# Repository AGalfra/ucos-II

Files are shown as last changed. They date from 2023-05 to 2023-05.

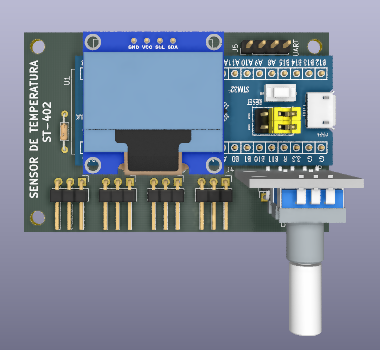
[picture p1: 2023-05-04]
vista2.png

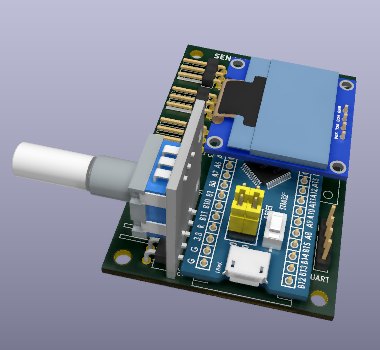
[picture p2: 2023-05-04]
vista3.png

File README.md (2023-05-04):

# ucos-II

## Sensor de Temperatura ST-1820

Introducción

Este dispositivo desarrollado en el presente informe es un medidor de temperaturas basado en sensores 1-Wire del tipo  capaz de medir hasta 4 sensores simultáneamente (aunque esta limitación está dada solo por configuración del firmware para adaptarla a las opciones del menú).
Tiene además la posibilidad de modificar la escala de medición, es decir, en ºC y ºF.
También es configurable la frecuencia de adquisición de los sensores (3, 5 o 10 segundos).
Para la visualización de las temperaturas se pueden elegir entre 2 modos de operación que serán descritos más adelante.

Diseño del PCB en Kicad
Desarrollo del firmware en STM32CubeIDE con kernel U/COS-II
Descripción
 
Para este proyecto se utilizó la placa de desarrollo Blue Pill que cuenta con un microprocesador ARM Cortex-M3 STM32F103C8T6 de ST Microelectronics en el cual se ha embebido el Kernel v2.9216. 

Además de la placa de desarrollo se han utilizado los siguientes elementos:

-Pantalla OLED SSD1306 128x64 pixeles de 0.96” con comunicación I2C.

-Encoder rotativo, que es utilizado para controlar el dispositivo.

-Sensores de temperatura del tipo 1-Wire como por ej. los DS18B20, DS1820 o DS18S20.

-UART para poder realizar una conexión con la PC (para un menú de diagnóstico).

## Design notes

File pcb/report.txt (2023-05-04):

Actualizado +3.3V de #PWR07 a #PWR04
Actualizado GND de #PWR08 a #PWR05
Actualizado +3.3V de #PWR09 a #PWR06
Actualizado GND de #PWR010 a #PWR07
Actualizado +3.3V de #PWR013 a #PWR08
Actualizado GND de #PWR014 a #PWR09
Actualizado GND de #PWR04 a #PWR010
Actualizado GND de #PWR05 a #PWR013
Actualizado +3.3V de #PWR06 a #PWR014
Actualizado Conn_01x03 de J5 a J4
Actualizado UART de J4 a J5

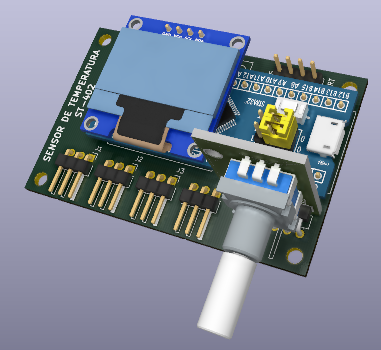
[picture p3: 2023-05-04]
vista1.png

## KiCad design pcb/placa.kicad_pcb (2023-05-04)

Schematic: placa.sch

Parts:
J1, J2, J3, J4: Conn_01x03; PinHeader_1x03_P2.54mm_Horizontal
J5: UART; PinHeader_1x04_P2.54mm_Vertical
J6: Encoder; Encoder_Rotativo
R1: 4K7; R_Axial_DIN0204_L3.6mm_D1.6mm_P7.62mm_Horizontal
U1: Blue_Pill
U2: SSD1306

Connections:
+3V3: J1.3, J2.3, J3.3, J4.3, J5.1, J6.2, R1.1, U1.18, U1.40, U2.2
/DQ: J1.2, J2.2, J3.2, J4.2, R1.2, U1.30
/EBUT: J6.3, U1.31
/ENCA: J6.4, U1.13
/ENCB: J6.5, U1.14
/RX: J5.2, U1.27
/SCL: U1.34, U2.3
/SDA: U1.35, U2.4
/TX: J5.3, U1.26
GND: J1.1, J2.1, J3.1, J4.1, J5.4, J6.1, U1.19, U1.20, U1.39, U2.1

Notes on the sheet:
BUS ONEWIRE

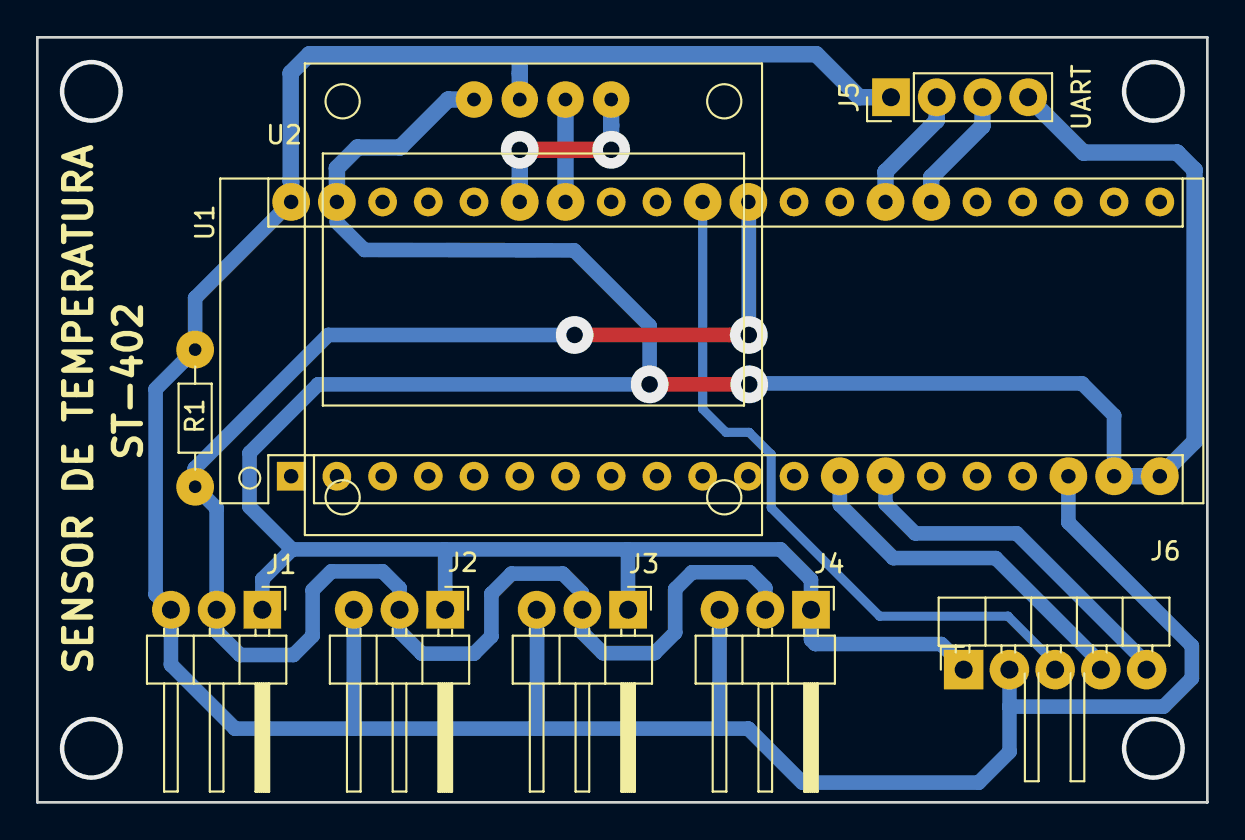
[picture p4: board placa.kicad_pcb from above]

Board: 2 copper layers, 65.0 x 42.5 mm, 9 parts (0 on the bottom side), 10 nets.

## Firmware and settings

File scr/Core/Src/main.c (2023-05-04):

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
/* Includes ------------------------------------------------------------------*/
#include "main.h"

/* USER CODE BEGIN Includes */

#include "includes.h"

/* USER CODE END Includes */

/* USER CODE BEGIN PD */
//#warning "Modify this value to match the number of external interrupts in your MCU"
#define EXT_INT_MAX_NBR 16u

/* USER CODE END PD */

I2C_HandleTypeDef hi2c1;

TIM_HandleTypeDef htim1;

UART_HandleTypeDef huart1;

/* USER CODE BEGIN PV */

BOOLEAN	Led;				// estado del LED pin
INT8U	CtxPerSec = 0;		// Cambios de contexto por segundo
char	ErrStr[35] = "";	// Str para debug de errores en eventos o funciones

/* USER CODE END PV */

void SystemClock_Config(void);
static void MX_GPIO_Init(void);
static void MX_I2C1_Init(void);
static void MX_TIM1_Init(void);
static void MX_USART1_UART_Init(void);
/**
  * @brief  The application entry point.
  * @retval int
  */
int main(void)
{
  /* USER CODE BEGIN 1 */
#if (OS_TASK_NAME_EN > 0u)
CPU_INT08U os_err;
#endif
CPU_INT16U int_id;
  /* USER CODE END 1 */

  /* MCU Configuration--------------------------------------------------------*/

  /* Reset of all peripherals, Initializes the Flash interface and the Systick. */
  HAL_Init();

  /* USER CODE BEGIN Init */
  CPU_IntDis();
  for (int_id = CPU_INT_EXT0; int_id <= (EXT_INT_MAX_NBR - 1u); int_id++)
  {
  /* Set all external intr. to KA interrupt priority boundary */
  CPU_IntSrcPrioSet(int_id, CPU_CFG_KA_IPL_BOUNDARY, CPU_INT_KA);
  }
  /* USER CODE END Init */

  /* Configure the system clock */
  SystemClock_Config();

  /* Initialize all configured peripherals */
  MX_GPIO_Init();
  MX_I2C1_Init();
  MX_TIM1_Init();
  MX_USART1_UART_Init();
  /* USER CODE BEGIN 2 */

  OSInit();
  os_err = OSTaskCreateExt( (void (*)(void *)) StartupTask,
  		  	  	  	 	 	 (void			*) 0,
  							 (OS_STK		*) &StartupTaskStk[APP_CFG_STARTUP_TASK_STK_SIZE - 1],
  							 (INT8U			 ) APP_CFG_STARTUP_TASK_PRIO,
  							 (INT16U		 ) APP_CFG_STARTUP_TASK_PRIO,
  							 (OS_STK		*) &StartupTaskStk[0],
  					 	 	 (INT32U		 ) APP_CFG_STARTUP_TASK_STK_SIZE,
  							 (void			*) 0,
  							 (INT16U		 ) (OS_TASK_OPT_STK_CHK | OS_TASK_OPT_STK_CLR));

  #if (OS_TASK_NAME_EN > 0u)
   OSTaskNameSet( APP_CFG_STARTUP_TASK_PRIO, (INT8U *)"Startup task", &os_err);
  #endif


  OSStart();
  /* USER CODE END 2 */

  /* Infinite loop */
  /* USER CODE BEGIN WHILE */
  while (1)
  {
    /* USER CODE END WHILE */

    /* USER CODE BEGIN 3 */
  }
  /* USER CODE END 3 */
}

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
/* USER CODE BEGIN 4 */
/*
*************************************************************************
* STM32Cube HAL FUNCTIONS
*************************************************************************
*/
HAL_StatusTypeDef HAL_InitTick(uint32_t TickPriority)
{
/* define as empty to prevent the system tick being initialized before
    the OS starts */
 return (HAL_OK);
}

uint32_t HAL_GetTick(void)
{
 CPU_INT32U os_tick_ctr;

 #if (OS_VERSION >= 30000u)
  OS_ERR os_err;
  os_tick_ctr = OSTimeGet(&os_err);
 #else
  os_tick_ctr = OSTimeGet();
 #endif

 return os_tick_ctr;
}

/* USER CODE END 4 */
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


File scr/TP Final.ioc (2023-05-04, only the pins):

Mcu.UserName=STM32F103C8Tx
PA0-WKUP.Signal=GPIO_Output
PA1.Signal=GPIO_Output
PA10.Signal=USART1_RX
PA13.Signal=SYS_JTMS-SWDIO
PA14.Signal=SYS_JTCK-SWCLK
PA2.Signal=GPIO_Output
PA9.Signal=USART1_TX
PB6.Signal=I2C1_SCL
PB7.Signal=I2C1_SDA
PC13-TAMPER-RTC.Signal=GPIO_Output
PD0-OSC_IN.Signal=RCC_OSC_IN
PD1-OSC_OUT.Signal=RCC_OSC_OUT

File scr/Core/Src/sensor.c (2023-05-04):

/*
*********************************************************************************************************
*									Modulo para Sensores DS18B20, DS1820, DS18S20
*
* 			NOTA: Para funcionar requiere de la libreria para comunicacion 1-Wire (onewire.h)
*
* Filename   : sensor.c
* Programmer : Alejandro Galfrascoli
*********************************************************************************************************
*/
/*
*********************************************************************************************************
*                                        		LIBRARIES
*********************************************************************************************************
*/
#include "includes.h"
/*
*********************************************************************************************************
*                                       		 VARIABLES
*********************************************************************************************************
*/

Ds18b20Sensor_t	ds18b20[DS18B20_MAX_SENSORS];		// Tabla de sensores
OneWire_t		OneWire;							// Instancia de la variable para el control del Bus
uint8_t			TempSensorCount = 0;				// cantidad de sensores detectados

/*
*********************************************************************************************************
*		                                          FUNCTION
*********************************************************************************************************
* @brief  Inicializa la tabla de sensores segun el resultados de la busqueda realizada.
* 		  NOTA: inicia el bus 1-Wire y lee la ROM de los sensores conectados
* @param  initFull: Si es 1 realiza la secuencia de inicializacion delbus 1-Wire.
* @retval NONE
*/
void DS18B20_Init(uint8_t initFull) {
	uint8_t next = 0, i = 0;

	if(initFull)
		OW_Init(&OneWire, DS18B20_GPIO_Port, DS18B20_Pin); 			// initFull = 1 -> Inicializar 1-Wire

	next = OW_First(&OneWire); 										// buscar el primer dispositivo
	while(next) {
		TempSensorCount++;
		OW_GetFullROM(&OneWire, (uint8_t*)&ds18b20[i++].Address);	// obtener la ROM del sensor
		next = OW_Next(&OneWire);									// buscar si hay mas dispositivos...
		if(TempSensorCount >= DS18B20_MAX_SENSORS)
			break;
	}
}

/*
*********************************************************************************************************
* @brief  Borra la tabla de sensores. Permite reenumerar los dispositivos nuevamente
* @param  Ds18b20Sensor_t*: puntero a la tabla de sensores
* @retval NONE
*/
void	DS18B20_Del(Ds18b20Sensor_t* sensors) {
	uint8_t i, j;

	for (i = 0; i < DS18B20_MAX_SENSORS; i++) {
		for (j = 0; j < 8; j++)
			sensors[i].Address[j] = 0;
		sensors[i].Temperature = 0;
		sensors[i].ValidDataFlag = 0;
	}
	TempSensorCount = 0;
}

/*
*********************************************************************************************************
* @brief  Inicia la conversion de temperatura para el sensor de indice num en la tabla de sensores.
* @param  num: el indice del sensor
* @retval 1: si se ejecutó el comando correctamente
* 		  0: si el indice es mayor que la cantidad de sensores o si no el dispositivo correspondiente no
* 		     es de la familia ds18xxx
*/
uint8_t DS18B20_Start(uint8_t num) {
	if( num >= TempSensorCount)								// compruebo que el indice es valido
		return 0;
	if (!DS18B20_Is18xxx((uint8_t*)&ds18b20[num].Address)) 	// Compruebo si el sensor es de la flia DS18B20
		return 0;

	OW_Reset(&OneWire); 									// Resetear el bus
	OW_Select(&OneWire, (uint8_t*)ds18b20[num].Address);	// Selecciono el sensor por su ROM
	OW_Write(&OneWire, DS18B20_CMD_CONVERTTEMP); 			// inicio Conversion
	return 1;
}

/*
*********************************************************************************************************
* @brief  Inicia la conversión de temperatura para todos los sensores
* @param  NONE
* @retval NONE
*/
void DS18B20_StartAll(void) {
	OW_Reset(&OneWire); 								// Resetear el bus
	OW_Write(&OneWire, CMD_SKIPROM); 					// comando Skip ROM
	OW_Write(&OneWire, DS18B20_CMD_CONVERTTEMP); 		// iniciar conversion
}

/*
*********************************************************************************************************
* @brief  Realiza la lectura del sensor y almacena la temperatura en la tabla de sensores.
* 		  NOTA: La temperatura es almacenada en formato raw 12bits.
* 		  NOTA: Se debe verificar el final de conversion antes de usar esta funcion.
* @param  num: indice del sensor
* @param  Ds18b20Sensor_t*: puntero a la tabla de sensores
* @retval devuelve 1 si el valor de la temperatura es valida o 0 si se produce un error
*/
uint8_t DS18B20_Read(uint8_t num, Ds18b20Sensor_t* sensor) {
	int16_t temp;
	uint8_t i = 0;
#if DS18B20_USE_CRC
	uint8_t crc;
#endif
	CPU_SR   cpu_sr;

	if( num >= TempSensorCount) 							// compruebo que el indice es valido
		return 0;
	if (!DS18B20_Is18xxx(sensor[num].Address)) 				// Compruebo si el sensor es de la flia DS18xxx
		return 0;

	OS_ENTER_CRITICAL();

	OW_Reset(&OneWire);										// Resetear el bus
	OW_Select(&OneWire, sensor[num].Address);				// Seleccionar el sensor por ROM
	OW_Write(&OneWire, CMD_RSCRATCHPAD); 					//  comando: Read Scratchpad
	for (i = 0; i < 9; i++) 								// Leer scratchpad
		sensor[num].ScratchPad[i] = OW_Read(&OneWire);

#if DS18B20_USE_CRC
	crc = OW_CRC8(data, 8); 				// Calcular CRC
	if (crc != &ds18b20[num].ScratchPad[8])
		return 0; 							// CRC invalido
#endif

	//OW_Reset(&OneWire);										// ver la necesidad de esta linea

	temp = (sensor[num].ScratchPad[0] << 3) | (sensor[num].ScratchPad[1] << 11);	// para modelo 18B20

	if(sensor[num].Address[0] == DS18S20MODEL) {			// para los modelos de 9 bits fijos... calculo
		temp = ((temp & 0xfff0) << 3) - 32					// segun hoja de datos la extension a 12bits
				+ (((sensor[num].ScratchPad[COUNT_PER_C] - sensor[num].ScratchPad[COUNT_REMAIN]) << 7)
				/ sensor[num].ScratchPad[COUNT_PER_C]);
	}
	sensor[num].Temperature = temp;							// temperatura en formato raw de 12bits
	OS_EXIT_CRITICAL();
	return 1; 												// temperatura valida
}

/*
*********************************************************************************************************
* @brief  Realiza la lectura de todos los sensores en la tabla de sensores.
* @param  NONE
* @retval NONE
*/
void DS18B20_ReadAll(void) {
	uint8_t i;

	if(DS18B20_AllDone(&OneWire)) {										// veifico final de conversion
		for(i = 0; i < TempSensorCount; i++) {
			ds18b20[i].ValidDataFlag = 0;
			ds18b20[i].ValidDataFlag = DS18B20_Read(i, ds18b20); 		// Leer cada sensor
		}
	}
}

/*
*********************************************************************************************************
* @brief  Verifica el primer byte de la Rom para saber si corresponde con el codigo de familia
* 		  de los dispositivos 18xxx soportados.
* @param  *ROM:	es un puntero a la ROM de dispositivo que se desea verificar.
* @retval    0: si NO es un modelo soportado.
* 			 1: SI es un modelo soportado.
*/
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

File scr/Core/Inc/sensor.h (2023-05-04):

/*
*********************************************************************************************************
*									Modulo para Sensores DS18B20, DS1820, DS18S20
*
* 			NOTA: Para funcionar requiere de la libreria para comunicacion 1-Wire (onewire.h)
*
* Filename   : sensor.h
* Programmer : Alejandro Galfrascoli
*********************************************************************************************************
*/

#ifndef INC_18B20_H_
#define INC_18B20_H_
/*
*********************************************************************************************************
*                                        		LIBRARIES
*********************************************************************************************************
*/
#include "includes.h"
/*
*********************************************************************************************************
*                                        CONFIGURATION CONSTANTS
*********************************************************************************************************
*/
#define DS18B20_MAX_SENSORS		    4				// Define Num max. de sensores en el Bus
#define DS18B20_Pin 				GPIO_PIN_15		// Define Pin a utilizar
#define DS18B20_GPIO_Port			GPIOA			// Define Puerto a utilizar

#define DS18B20_USE_CRC				0				// Habilita la compilacion de codigo para CRC
#define DS18B20_USE_SET_RESOLUTION	0				// Habilita la compilacion de codigo para GetResolution()
#define DS18B20_USE_GET_RESOLUTION	0				// Habilita la compilacion de codigo para SetResolution()
//----------------------------------------------
#define DS18B20_CMD_ALARMSEARCH		0xEC
#define DS18B20_CMD_CONVERTTEMP		0x44
// Resolution
#define DS18B20_STEP_12BIT			0.0625
#define DS18B20_STEP_11BIT			0.125
#define DS18B20_STEP_10BIT			0.25
#define DS18B20_STEP_9BIT			0.5
// Device resolution
#define TEMP_9_BIT  				0x1F 					//  9 bit
#define TEMP_10_BIT 				0x3F 					// 10 bit
#define TEMP_11_BIT	 				0x5F 					// 11 bit
#define TEMP_12_BIT 				0x7F 					// 12 bit
// IDs de modelos soportados
#define DS18S20MODEL 				0x10  					// Tambien para el DS1820
#define DS18B20MODEL				0x28  					// Tambien para el MAX31820
#define DS1822MODEL  				0x22
#define DS1825MODEL  				0x3B
// Scratchpad locations
#define TEMP_LSB       				0
#define TEMP_MSB        			1
#define HIGH_ALARM_TEMP 			2
#define LOW_ALARM_TEMP  			3
#define CONFIGURATION   			4
#define INTERNAL_BYTE   			5
#define COUNT_REMAIN    			6
#define COUNT_PER_C     			7
#define SCRATCHPAD_CRC  			8

#define DS18B20_RESOLUTION_R1		6 						// Resolucion bit R1
#define DS18B20_RESOLUTION_R0		5 						// Resolucion bit R0
/*
*********************************************************************************************************
*                                            DATA TYPES
*********************************************************************************************************
*/
typedef struct {
	uint8_t 	Address[8];						// direccion ROM del Dispositivo
	uint8_t		ScratchPad[9];					// ScratchPad del dispositivo
	int16_t		Temperature;					// Temperaura en formato raw 12bits
	uint8_t		ValidDataFlag;					// vale 1 Si la temperatura es valida
} Ds18b20Sensor_t;

typedef enum {
	DS18B20_Resolution_9bits = 9,
	DS18B20_Resolution_10bits = 10,
	DS18B20_Resolution_11bits = 11,
	DS18B20_Resolution_12bits = 12
} DS18B20_Resolution_t;

/*
*********************************************************************************************************
*                                          FUNCTION PROTOTYPES
*********************************************************************************************************
*/
void	DS18B20_Init(uint8_t initFull);
void	DS18B20_Del(Ds18b20Sensor_t* sensors);
// Control
uint8_t DS18B20_Start(uint8_t num); 											// Iniciar la conversión de un sensor
void 	DS18B20_StartAll(void);													// Iniciar la conversión de todos los sensores
uint8_t	DS18B20_Read(uint8_t num, Ds18b20Sensor_t* sensor);						// Leer un sensor
void 	DS18B20_ReadAll(void);													// Leer todos los sensores conectados
uint8_t DS18B20_Is18xxx(uint8_t* ROM); 											// Compruebe si la ROM es de la familia DS18xxx
uint8_t DS18B20_AllDone(OneWire_t* onewire);									// Comprueba si se realizó la conversión de todos los sensores

#if DS18B20_USE_GET_RESOLUTION
uint8_t DS18B20_GetResolution(uint8_t num, Ds18b20Sensor_t* sensor);			// Obtener la resolución del sensor
#endif
#if DS18B20_USE_SET_RESOLUTION
uint8_t DS18B20_SetResolution(uint8_t num, DS18B20_Resolution_t resolution);	// Establecer la resolución del sensor
#endif

//	ROMs
void	DS18B20_GetROM(uint8_t num, uint8_t* ROM); 		// Obtener la ROM del sensor de id 'num'
void	DS18B20_WriteROM(uint8_t num, uint8_t* ROM); 	// Escribe una ROM en la posición de 'num' en la tabla de sensores
// Funciones de retorno
uint8_t DS18B20_Quantity(void);							// Devuelve la cantidad de sensores conectados
uint8_t	DS18B20_GetTempC(uint8_t num, float* res); 		// Obtener la temp. de un sensor en °C
uint8_t	DS18B20_GetTempF(uint8_t num, float* res); 		// Obtener la temp. de un sensoren °F

/*
*********************************************************************************************************
*/
#endif /* INC_18B20_H_ */

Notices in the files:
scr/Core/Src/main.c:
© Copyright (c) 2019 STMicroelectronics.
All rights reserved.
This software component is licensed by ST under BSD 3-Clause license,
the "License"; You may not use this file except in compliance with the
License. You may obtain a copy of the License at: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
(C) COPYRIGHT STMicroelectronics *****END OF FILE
